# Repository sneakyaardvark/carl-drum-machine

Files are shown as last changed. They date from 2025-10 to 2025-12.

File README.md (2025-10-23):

# C.A.R.L. — Clocked Asynchronous Rhythm Logician

**Team 05:**  
Bao Nguyen  
Andrew Stanton  
Christian Mickelson  
Ethan Budde  

---

## Overview
C.A.R.L. is a portable drum sequencer that lets users tap out, save, and play rhythmic patterns. It operates independently with onboard controls, display, and speaker.

---

## Features
- Sequences and plays drum beats  
- Onboard speaker and volume control  
- Standalone operation (no computer required)  
- 13 pushbuttons, LED indicators, LCD display  
- Optional MIDI, SD card, and battery power  

---

## Hardware
- **Processor:** ESP32  
- **Display:** 20×4 LCD  
- **Inputs:** 13 pushbuttons, 4 potentiometers  
- **Outputs:** LEDs, speaker (8 Ω), LCD  
- **Power:** 5 V barrel jack or optional battery  
- **Enclosure:** Laser-cut plywood + 3D printed parts  

---

## Development
- **Electronics:** KiCAD  
- **3D Design:** Fusion 360  
- **Firmware:** Arduino / PlatformIO

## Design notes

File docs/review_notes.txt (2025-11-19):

Team 8 reviews Team 5 11/18/2025
Nawaf, Nawaf
Andrew, Ethan, Christian, Bao

Number of sensors
 - 8 buttons for beat, each with 2 LEDs
 - Function buttons, play has 1 LED

Power supply
 - multiple regulators: 5V and 3.3V
 - multiple of each for temperature management
 - calculate power consumption
 - Use diodes for feedback / reverse polarity
 - 100uF or less caps close to ICs (decoupling caps)
 - USBC for power?
 - 0.5 for power traces
 - 0.3 for everything else

LED driver
 - 1 resistor controls voltage to all LEDs

Use different switch for power toggle (keyboard switch won't work)

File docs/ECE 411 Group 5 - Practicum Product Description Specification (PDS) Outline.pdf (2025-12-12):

### Team 05

Bao Nguyen
Andrew Stanton
Christian Mickelson
Ethan Budde
Practicum Product Design Specification (PDS)
- Short Descriptive Name
- C.A.R.L.: The Clocked Asynchronous Rhythm Logician, a drum machine made to interactively and portably create sequences of musical beats.
- Executive Summary with Concept of Operations (2 pts)
- A portable drum sequencer that plays and saves music sequences. Users can tap out a drum beat, save and clone patterns, and play back their beats through the on-board speaker. [Users can also apply basic effects and modulation to the sequence, for added customizability.]
- Brief “Market” Analysis (2 pts)
- Who are the intended customers / users?
■ Music students, hobbyists, and sound producers of all kinds.
- What is the competition? Why is your product different?
■ Competing with large name-brand musical equipment manufacturers (Korg, Yamaha, Roland, etc)
■ Also competing with more niche, hobbyist sound engineering products (teenage engineering, Analogue)
■ Our product/software is open source and customizable
■ No subscriptions, payment plans, DRM
■ No warranty-voiding internal hardware, fully repairable and destroyable!
- What price do you think you can sell this for, and why? (keep it short, we're engineers, not marketing researchers)
■ 50 dollars, since most commercial options are over $100.
- Requirements (4 pts)
- Must sequence music beats
- Must play back sequenced beats
- Must include a speaker
- Must include volume adjustment
- Must operate independently of a computer or other audio equipment
- Must have buttons for parameter changes
- Should have audio effects
- Should be contained in an enclosure
- Should have MIDI output
- Should have multiple tracks / polyphonic sound
- Should have display for polyphonic voice / pattern parameters
- May have audio line out
- May allow the user to add new sounds
- May be battery powered

- System Architecture (4 pts)
- Level 0

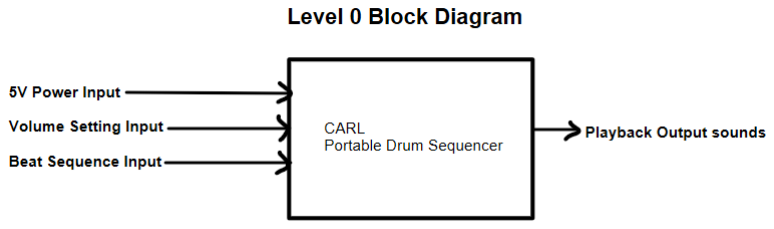
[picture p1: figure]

- Level 1

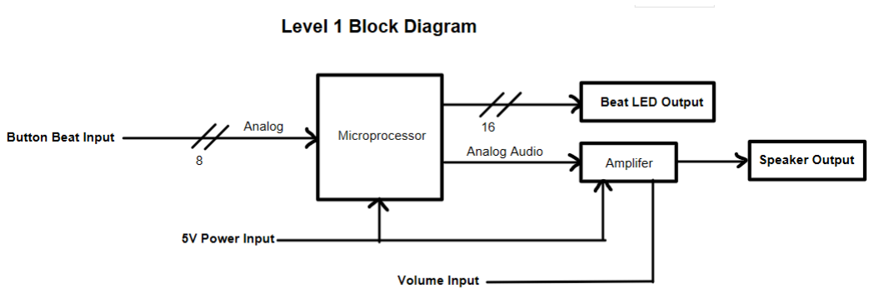
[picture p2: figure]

- Design Specification (4 pts)
- Sensors
■ Buttons: basic small switches ■ Volume: potentiometer
- Processor: ESP32
■ Firmware: Arduino framework
- Actuators
■ Beat LEDs
■ Speaker (8ohm speaker)
- Power
■ 5V from wall adapter
■ Optional battery power
- Mechanical Design
■ Enclosure: laser Cut plywood + 3d printed components
- Development environment
■ KiCAD
■ Fusion360
■ PlatformIO

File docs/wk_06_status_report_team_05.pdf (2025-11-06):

ECE411 HW Wk 06
Team 05
Bao Nguyen
Andrew Stanton
Christian Mickelson
Ethan Budde
Status Report: CARL Drum Machine The CARL drum machine MVP(Minimum Viable Product) is on-track for completion. There is a basic breadboard prototype for the controls and power supply, while the development boards for the audio components were delayed in shipping. They should arrive by the end of the week. The schematic and PCB layout are also going well. All necessary components are present and work can begin on polishing. The firmware is going very well, with a good framework and a number of abstractions already in place. Now that the hardware is well defined, the “glue” can be coded to tie the framework together with the hardware. Even with reasonable debug time, there should be time for extra features, such as multiple voices/polyphony.

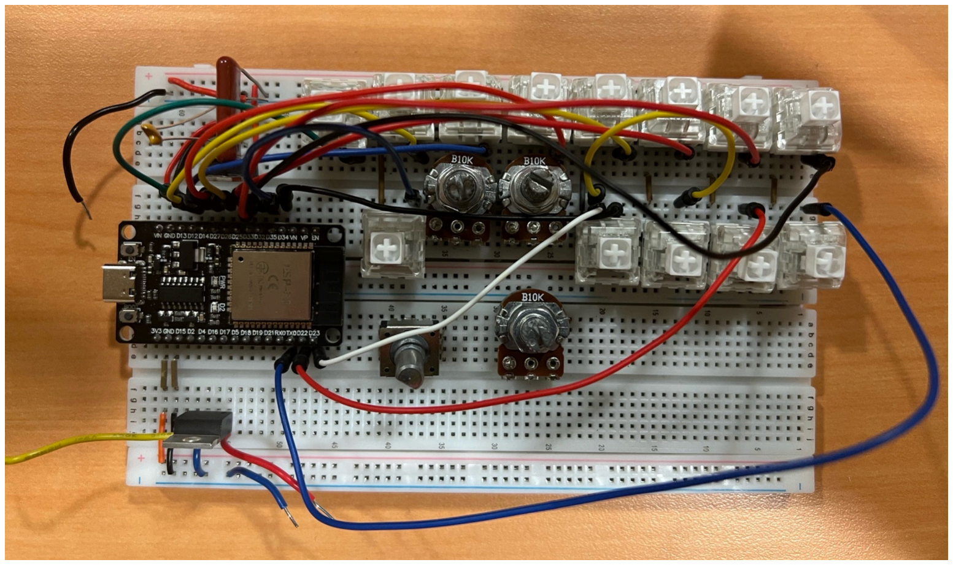
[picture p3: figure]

Breadboard prototype #1

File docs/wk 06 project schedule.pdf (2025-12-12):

ECE411 HW Wk 06
Team 05
Bao Nguyen
Andrew Stanton
Christian Mickelson
Ethan Budde
Project Schedule
We are using a GitHub project to manage our tasks and schedule. It is available here: https://github.com/users/sneakyaardvark/projects/1/views/4
Here is a preview screenshot (no .pdf export is available, sorry!)

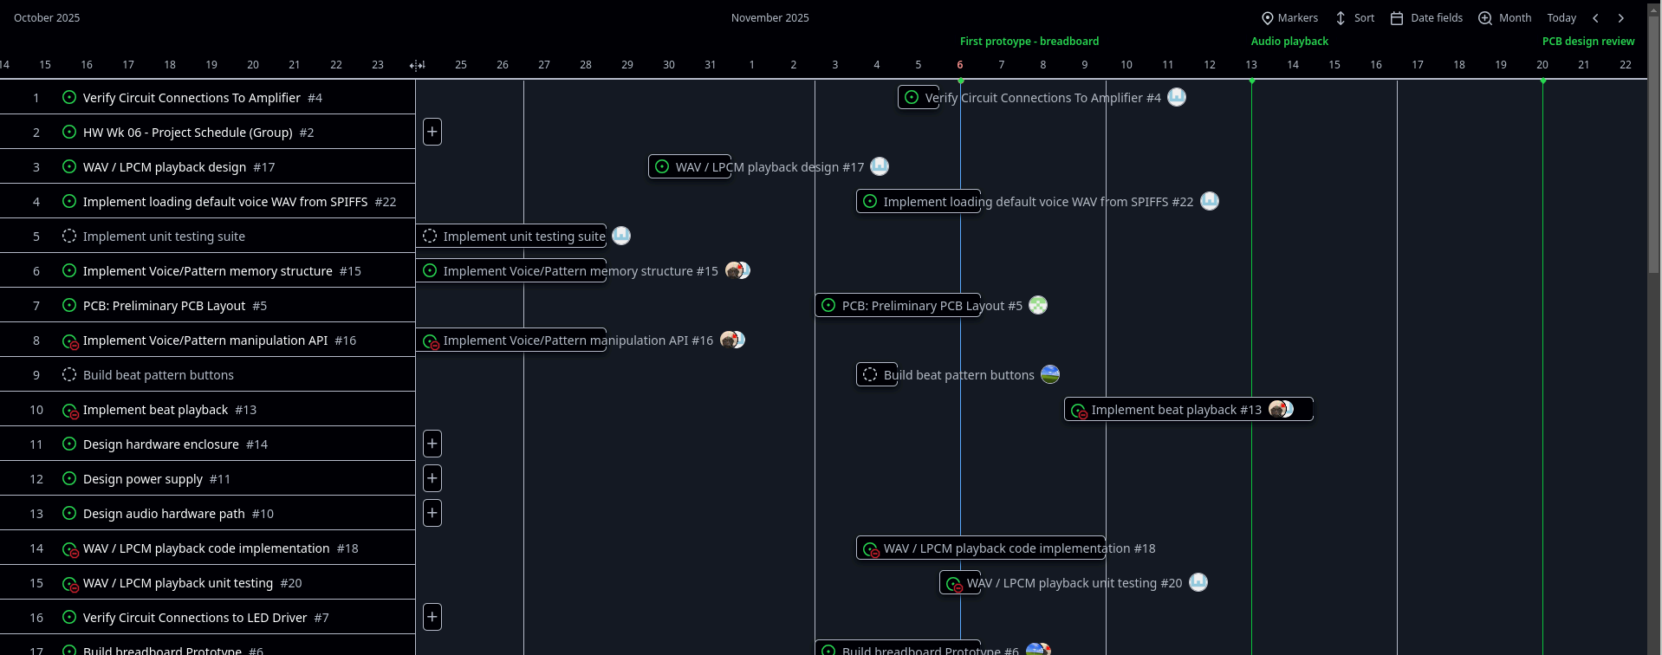
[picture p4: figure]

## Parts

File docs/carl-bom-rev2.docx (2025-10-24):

C.A.R.L. Drum Machine BOM
Rev. 2

# | Item Description | Qty | Function / Notes

1 | 8 Ω Speaker | 1 | Audio output
2 | Clear Plastic NO pushbuttons | 17 | Momentary inputs for user control
3 | Red LEDs | 8 | Visual feedback for downbeat notes
4 | Yellow LEDs | 8 | Visual feedback for backbeat notes
5 | Green LED | 1 | Playback indicator / metronome visualization
6 | Orange LED | 1 | MOD button indicator
7 | Potentiometers | 4 | Control parameters (volume, tempo, filtering)
8 | 20x5 LCD Display | 1 | System information display (voices, patterns)
9 | Speaker Op-Amp | 1 | Amplifying speaker output
10 | Fuses | 8 | Current fluctuation protection
11 | E-pin Jumpers | 4 | Debugging / circuit-level isolation
12 | Knobs | 4 | Potentiometer control
13 | 3.5 mm Audio Jack | 1 | Output for external audio device
14 | 2.5 mm Barrel Jack | 1 | DC power input port
15 | 9V Battery Terminals | 2 | Battery power input ports
16 | LED Driver | 1 | Arbitrate LED brightness and sequencing
17 | 3.3/5 V PS/MP Board | 1 | Power supplier / main control board
18 | SD Card Reader | 1 | External memory interface
19 | ESP32 Processor | 1 | Primary logic controller

ECE411 Group 5 Bao Nguyen Andrew Stanton Christian Mickelson Ethan Budde

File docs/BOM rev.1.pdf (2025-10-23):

# BOM rev.1

# | Item Description | Qty | Notes / Function

1 | 8 Ω Speaker | 1 | Audio output
2 | Clear Plastic Pushbuttons (N/O) - Keyboard type | 13 | Momentary inputs for user control
3 | Red LEDs (onbeat) | 8 | Visual beat indicators
4 | Orange/Yellow LEDs (offbeat) | 8 | Secondary timing indicators
5 | Green LED (power) | 1 | Power indicator
6 | Potentiometers | 4 | Control parameters (e.g. volume, filter, etc.)
7 | LCD Display (20×4 or 20×5) | 1 | System display
8 | Speaker Op-Amp | 1 | Amplifies speaker output
9 | Fuses | 8 | Over-current protection
10 | Jumpers (E-pin) | 4 | Debugging/isolation
11 | Knobs | 4 | For potentiometer shafts
12 | 3.5 mm Jack | 1 | Audio I/O
13 | Barrel Jack | 1 | DC power input
14 | LED Driver | 1 | Controls LED brightness and sequencing
15 | PS/MP Board (5 V / 3.3 V) | 1 | Power supply / main control board
16 | SD Card Reader | 1 | External memory interface
17 | ESP32 | 1 | Main microcontroller

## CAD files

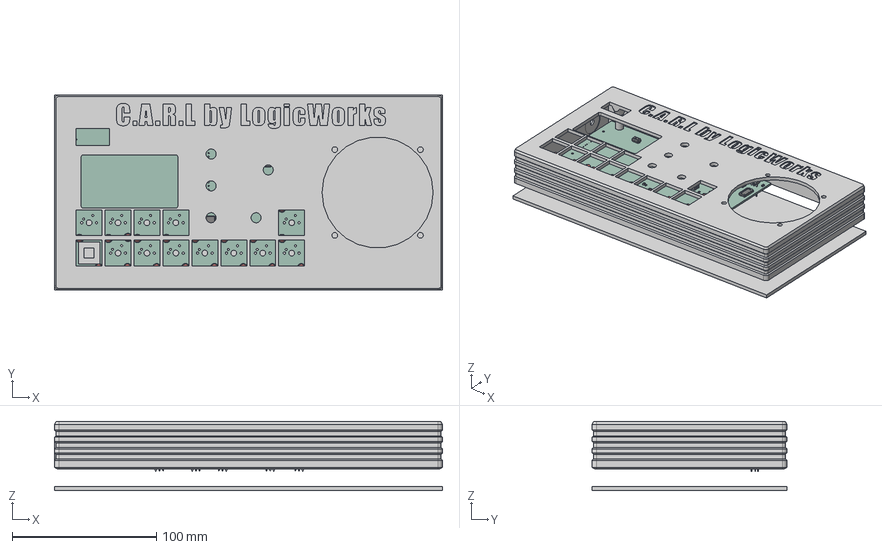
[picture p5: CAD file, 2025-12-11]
3D Models/Carl_Enclosure.step
269.0 x 135.0 x 48.0 mm
LED_D5.0mm x 18
HTSSOP-32-1EP_6.1x11mm_P0.65mm_EP5.2x11mm
C_0805_2012Metric x 15
PinHeader_1x02_P2.54mm_Vertical x 7
PinHeader_1x01_P2.54mm_Vertical x 9
TO-220-3_Vertical x 5
SOIC-28W_7.5x17.9mm_P1.27mm
R_0805_2012Metric x 4
SW_DIP_SPSTx01_Slide_6.7x4.1mm_W6.73mm_P2.54mm_LowProfile_JPin
Speaker_CUI_CMR-1206S-67
CARL_PCB

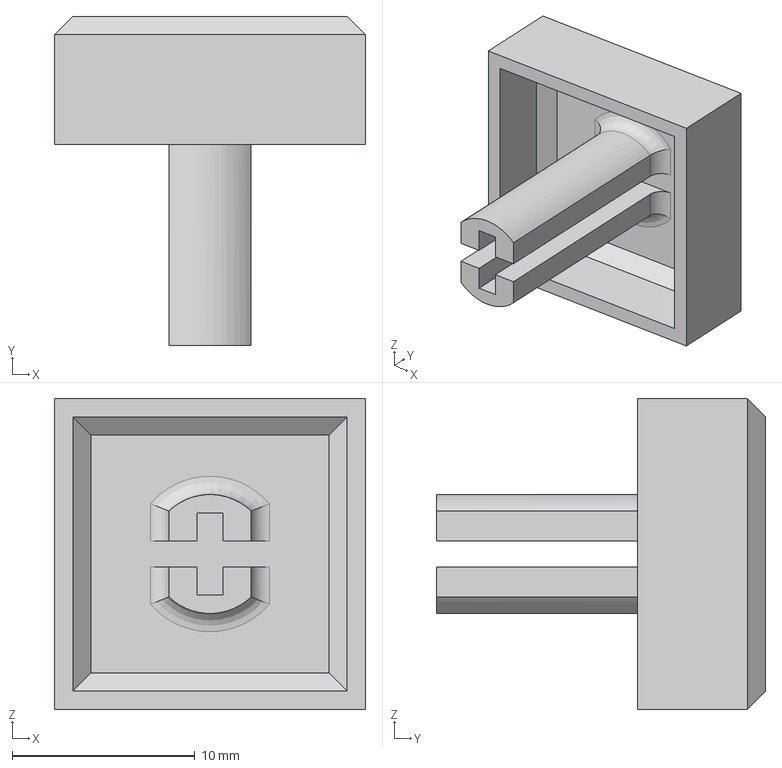
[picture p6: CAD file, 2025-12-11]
3D Models/Carl_Keycap.step
17.0 x 18.0 x 17.0 mm

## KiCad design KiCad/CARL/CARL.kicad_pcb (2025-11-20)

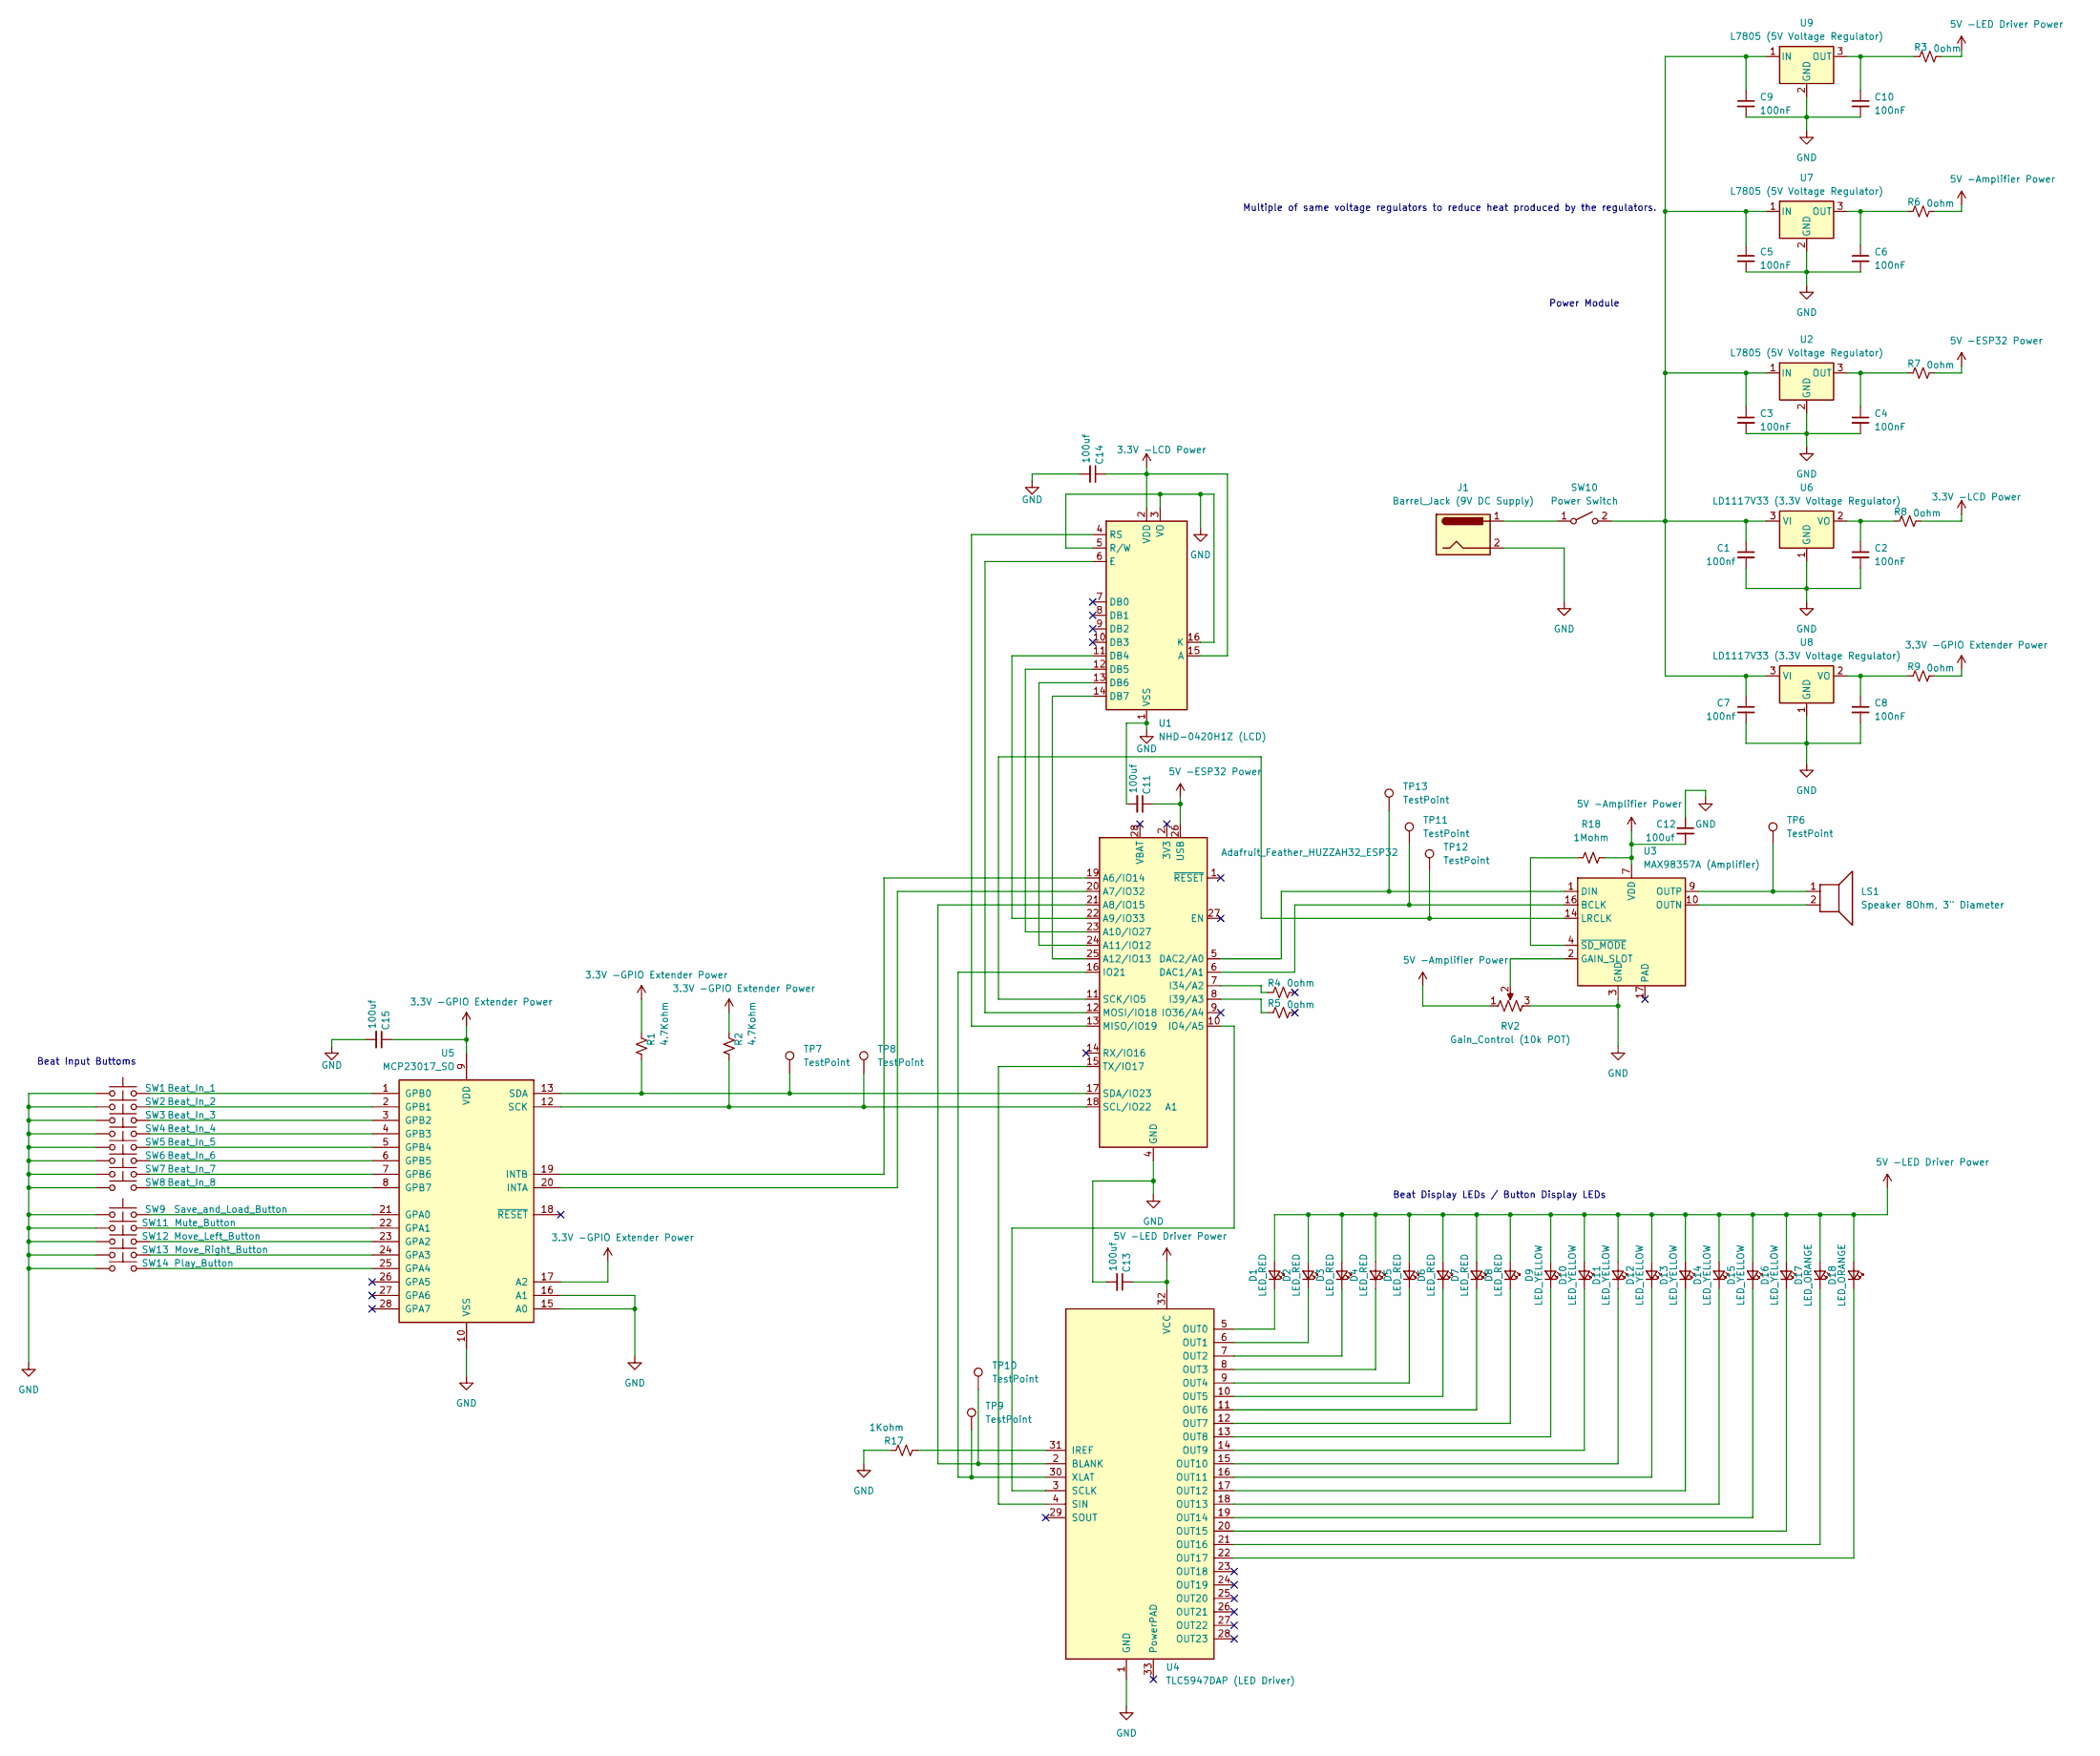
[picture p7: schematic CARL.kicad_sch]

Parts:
A1: Adafruit_Feather_HUZZAH32_ESP32; Adafruit_Feather
C1, C7: 100nf; C_0805_2012Metric
C2, C3, C4, C5, C6, C8, C9, C10: 100nF; C_0805_2012Metric
C11, C12, C13, C14, C15: 100uf; C_0805_2012Metric
D1, D2, D3, D4, D5, D6, D7, D8: LED_RED; LED_D5.0mm
D9, D10, D11, D12, D13, D14, D15, D16: LED_YELLOW; LED_D5.0mm
D17, D18: LED_ORANGE; LED_D5.0mm
J1: Barrel_Jack (9V DC Supply); BarrelJack_CUI_PJ-036AH-SMT_Horizontal
LS1: Speaker 8Ohm, 3" Diameter; Speaker_CUI_CMR-1206S-67
R1, R2: 4.7Kohm; R_0805_2012Metric
R3, R4, R5, R6, R7, R8, R9: 0ohm; PinHeader_1x02_P2.54mm_Vertical
R17: 1Kohm; R_0805_2012Metric
R18: 1Mohm; R_0805_2012Metric
RV2: Gain_Control (10k POT); Potentiometer_ACP_CA6-VSMD_Vertical
SW1: Beat_In_1; SW_Cherry_MX_1.00u_PCB
SW2: Beat_In_2; SW_Cherry_MX_1.00u_PCB
SW3: Beat_In_3; SW_Cherry_MX_1.00u_PCB
SW4: Beat_In_4; SW_Cherry_MX_1.00u_PCB
SW5: Beat_In_5; SW_Cherry_MX_1.00u_PCB
SW6: Beat_In_6; SW_Cherry_MX_1.00u_PCB
SW7: Beat_In_7; SW_Cherry_MX_1.00u_PCB
SW8: Beat_In_8; SW_Cherry_MX_1.00u_PCB
SW9: Save_and_Load_Button; SW_Cherry_MX_1.00u_PCB
SW10: Power Switch; SW_DIP_SPSTx01_Slide_6.7x4.1mm_W6.73mm_P2.54mm_LowProfile_J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
SW11: Mute_Button; SW_Cherry_MX_1.00u_PCB
SW12: Move_Left_Button; SW_Cherry_MX_1.00u_PCB
SW13: Move_Right_Button; SW_Cherry_MX_1.00u_PCB
SW14: Play_Button; SW_Cherry_MX_1.00u_PCB
TP6, TP7, TP8, TP9, TP10, TP11, TP12, TP13: TestPoint; PinHeader_1x01_P2.54mm_Vertical
U1: NHD-0420H1Z (LCD); NHD-0420H1Z
U2, U7, U9: L7805 (5V Voltage Regulator); TO-220-3_Vertical
U3: MAX98357A (Amplifier); TQFN-16-1EP_3x3mm_P0.5mm_EP1.23x1.23mm
U4: TLC5947DAP (LED Driver); HTSSOP-32-1EP_6.1x11mm_P0.65mm_EP5.2x11mm_Mask4.11x4.36mm_T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
U5: MCP23017_SO; SOIC-28W_7.5x17.9mm_P1.27mm
U6, U8: LD1117V33 (3.3V Voltage Regulator); TO-220-3_Vertical

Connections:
3.3V -GPIO Extender Power: C15.1, R1.1, R2.1, R9.2, U5.9 (VDD), U5.17 (A2)
3.3V -LCD Power: C14.1, R8.2, U1.2 (VDD), U1.15 (A); also elsewhere on the board
5V -Amplifier Power: C12.2, R6.2, R18.2, RV2.1, U3.7 (VDD), U3.8 (VDD)
5V -ESP32 Power: A1.26 (USB), C11.1, R7.2
5V -LED Driver Power: C13.1, D1.2 (A), D2.2 (A), D3.2 (A), D4.2 (A), D5.2 (A), D6.2 (A), D7.2 (A), D8.2 (A), D9.2 (A), D10.2 (A), D11.2 (A), D12.2 (A), D13.2 (A), D14.2 (A), D15.2 (A), D16.2 (A), D17.2 (A), D18.2 (A), R3.2, U4.32 (VCC)
GND: A1.4 (GND), C1.2, C2.2, C3.2, C4.2, C5.2, C6.2, C7.2, C8.2, C9.2, C10.2, C11.2, C12.1, C13.2, C14.2, C15.2, J1.2, R17.1, RV2.3, SW1.1, SW2.1, SW3.1, SW4.1, SW5.1, SW6.1, SW7.1, SW8.1, SW9.1, SW11.1, SW12.1, SW13.1, SW14.1, U1.1 (VSS), U1.3 (VO), U1.5 (R/W), U1.16 (K), U2.2 (GND), U3.3 (GND), U3.11 (GND), U3.15 (GND), U4.1 (GND), U5.10 (VSS), U5.15 (A0), U5.16 (A1), U6.1 (GND), U7.2 (GND), U8.1 (GND), U9.2 (GND)
unnamed: A1.19 (A6/IO14), U5.19 (INTB)
unnamed: A1.20 (A7/IO32), U5.20 (INTA)
unnamed: A1.21 (A8/IO15), TP10.1, U4.2 (BLANK)
unnamed: A1.22 (A9/IO33), U1.11 (DB4)
unnamed: A1.23 (A10/IO27), U1.12 (DB5)
unnamed: A1.24 (A11/IO12), U1.13 (DB6)
unnamed: A1.25 (A12/IO13), U1.14 (DB7)
unnamed: A1.6 (DAC1/A1), TP11.1, U3.16 (BCLK)
unnamed: A1.5 (DAC2/A0), TP13.1, U3.1 (DIN)
unnamed: A1.7 (I34/A2), R4.1
unnamed: A1.8 (I39/A3), R5.1
unnamed: A1.10 (IO4/A5), U4.3 (SCLK)
unnamed: A1.16 (IO21), TP9.1, U4.30 (XLAT)
unnamed: A1.13 (MISO/IO19), U1.4 (RS)
unnamed: A1.12 (MOSI/IO18), U1.6 (E)
unnamed: A1.11 (SCK/IO5), TP12.1, U3.14 (LRCLK)
unnamed: A1.18 (SCL/IO22), R2.2, TP8.1, U5.12 (SCK)
unnamed: A1.17 (SDA/IO23), R1.2, TP7.1, U5.13 (SDA)
unnamed: A1.15 (TX/IO17), U4.4 (SIN)
unnamed: D1.1 (K), U4.5 (OUT0)
unnamed: D2.1 (K), U4.6 (OUT1)
unnamed: D3.1 (K), U4.7 (OUT2)
unnamed: D4.1 (K), U4.8 (OUT3)
unnamed: D5.1 (K), U4.9 (OUT4)
unnamed: D6.1 (K), U4.10 (OUT5)
unnamed: D7.1 (K), U4.11 (OUT6)
unnamed: D8.1 (K), U4.12 (OUT7)
unnamed: D9.1 (K), U4.13 (OUT8)
unnamed: D10.1 (K), U4.14 (OUT9)
unnamed: D11.1 (K), U4.15 (OUT10)
unnamed: D12.1 (K), U4.16 (OUT11)
unnamed: D13.1 (K), U4.17 (OUT12)
unnamed: D14.1 (K), U4.18 (OUT13)
unnamed: D15.1 (K), U4.19 (OUT14)
unnamed: D16.1 (K), U4.20 (OUT15)
unnamed: D17.1 (K), U4.21 (OUT16)
unnamed: D18.1 (K), U4.22 (OUT17)
unnamed: J1.1, SW10.1 (A)
unnamed: C1.1, C3.1, C5.1, C7.1, C9.1, SW10.2 (B), U2.1 (IN), U6.3 (VI), U7.1 (IN), U8.3 (VI), U9.1 (IN)
unnamed: C4.1, R7.1, U2.3 (OUT)
unnamed: RV2.2, U3.2 (GAIN_SLOT)
unnamed: LS1.2, U3.10 (OUTN)
unnamed: LS1.1, TP6.1, U3.9 (OUTP)
unnamed: R18.1, U3.4 (~SD_MODE)
unnamed: R17.2, U4.31 (IREF)
unnamed: SW9.2, U5.21 (GPA0)
unnamed: SW11.2, U5.22 (GPA1)
unnamed: SW12.2, U5.23 (GPA2)
unnamed: SW13.2, U5.24 (GPA3)
unnamed: SW14.2, U5.25 (GPA4)
unnamed: SW1.2, U5.1 (GPB0)
unnamed: SW2.2, U5.2 (GPB1)
unnamed: SW3.2, U5.3 (GPB2)
unnamed: SW4.2, U5.4 (GPB3)
unnamed: SW5.2, U5.5 (GPB4)
unnamed: SW6.2, U5.6 (GPB5)
unnamed: SW7.2, U5.7 (GPB6)
unnamed: SW8.2, U5.8 (GPB7)
unnamed: C2.1, R8.1, U6.2 (VO)
unnamed: C6.1, R6.1, U7.3 (OUT)
unnamed: C8.1, R9.1, U8.2 (VO)
unnamed: C10.1, R3.1, U9.3 (OUT)

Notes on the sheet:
Beat Input Buttoms
Multiple of same voltage regulators to reduce heat produced by the regulators.
Power Module
Beat Display LEDs / Button Display LEDs

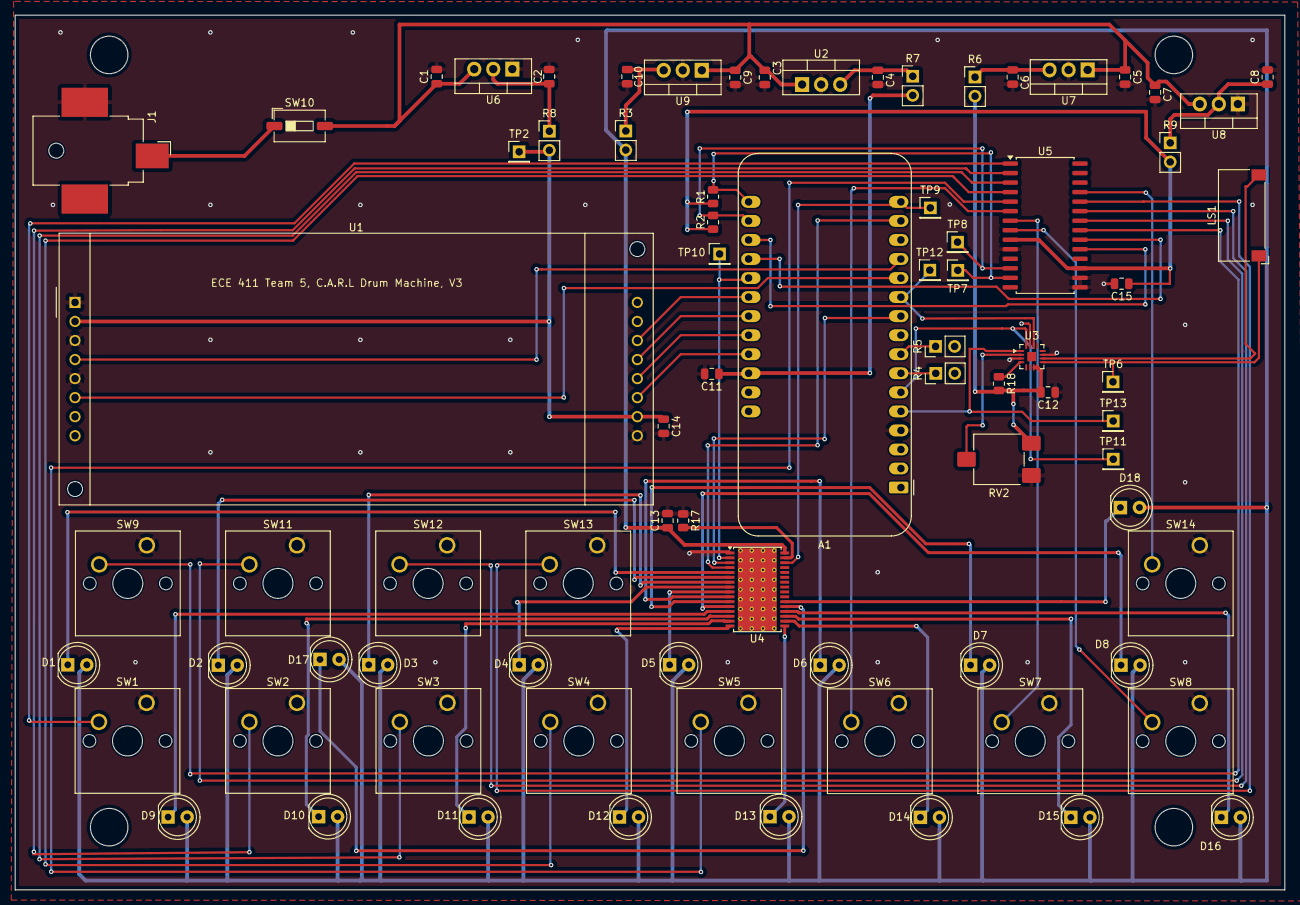
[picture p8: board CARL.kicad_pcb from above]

Board: 2 copper layers, 169.3 x 116.7 mm, 80 parts (0 on the bottom side), 68 nets.

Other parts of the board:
TP2: TestPoint; PinHeader_1x01_P2.54mm_Vertical

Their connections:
3.3V -LCD Power: TP2.1; also elsewhere on the board

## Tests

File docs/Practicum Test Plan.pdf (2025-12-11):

Project Title: CARL
Team Name: Group 5
Team Members: Andrew Stanton, Bao Nguyen, Christian Mickelson, Ethan Budde Date:12/3/2025

Practicum Test Plan
This test plan is an outline on how C.A.R.L drum machines will be tested to make sure it works as designed. This document includes a test for each sub system, verification test for the main functions, and validation test showing the final system meets all project requirements. The goal is to confirm every part of the design from power, inputs, and outputs functions correctly and reliably in the finished product.

### Unit Testing

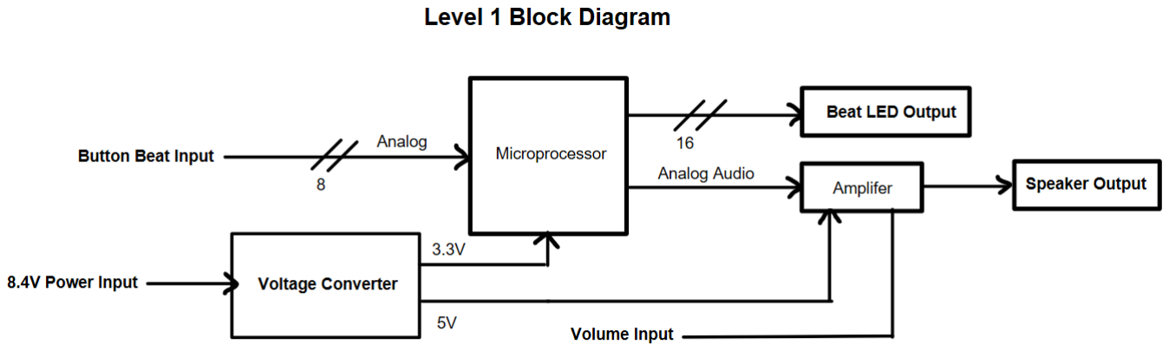
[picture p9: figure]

Fig 1. L1 block diagram

Unit Test ID | Block ID | Test Description
UT-01 | 2s Power Input | Verify 2s power are being delivered to 5V and 3V Voltage Regulator
UT-02 | 5V Power Output | Verify 5V out for the LED driver and Amplifier
UT-03 | 3V Power Output | Verify 3V out for the Microprocessor, LCD, and GPIO expander
UT-04 | Beat Button Input | Confirm Pressing the button sends digital signal to uP
UT-05 | Volume Pot | Verify volume is adjustable Via Pot
UT-06 | Beat LED Output | Verify Beat LED output expected behavior based on button inputs.
UT-07 | Amplifier | Verify Ampliter increase audio signal
UT-08 | Speaker Output | Confirm speaker output sound
UT-09 | Micropressesor | Test GPIO outputs with a logic analyzer

### Verification Test

Verification Test ID | Function / Feature | Test Description
VT-01 | Beat Button input | Verify pressing beat buttons record beat into the sequencer
VT-02 | Sequence playback | After VT-01, press play and observe the selected beats play back
VT-03 | Volume Control | Check that adjusting the volume knob changes the volume of the output sound
VT-04 | Beat LED | Verify the Beat LED flashes in respect to the sequencer clock
VT-05 | Pattern saving/cloning | After VT-01, press the save button, cycle to a different track, and paste. Observe that the same pattern is copied to the new track
VT-06 | Pattern switching | Confirm the switching pattern updates playback to the new pattern
VT-07 | System start up | Make sure it turns on in a default state.
VT-08 | Speaker output check | Verify speaker output is clean audio sound.

### Validation Tests

Validation Test ID | Requirement(Must/Should/May) | Validation Test Description
VAL-01 | Must sequence music beats | Verify that the user can enter a series of button presses and the system stores them as a beat sequence.
VAL-02 | Must play back sequenced beats | Confirm that a stored beat sequence can be played back in a repeating loop through the speaker.
VAL-03 | Must include a speaker | Verify that the product enclosure includes a functioning speaker connected to the audio output.
VAL-04 | Must include volume adjustment | Confirm that the user can adjust the volume and that the audio level changes over a usable range.
VAL-05 | Must operate independently of a computer or other audio equipment | Verify that the system can power on, sequence, and play beats with only its own power source and controls.
VAL-06 | Must have buttons for parameter changes | Confirm that physical buttons exist for changing parameters and that each button reliably changes at least one parameter.
VAL-07 | Must be contained in an enclosure | Verify that all electronics are mounted in a physical enclosure suitable for normal handling and use.
VAL-08 | Should have audio effects | Confirm that at least one audio effect can be enabled and that it audibly changes the output.

VAL-09 | Should have MIDI output | Verify that MIDI output signals are produced according to documented mapping when beats are played.
VAL-10 | Should have multiple tracks | Confirm that at least two different sounds can play simultaneously in a single pattern.
VAL-11 | Should have display for polyphonic voice | Verify that the display shows information about tracks/voices or pattern parameters while editing/playing.
VAL-12 | May have audio line out | Confirm that, if implemented, an audio line-out jack produces the same signal as the speaker output at line level.
VAL-13 | May allow the user to add new sounds | Verify that the user can load or select new sounds and use them in a sequence.
VAL-14 | May be battery powered | Confirm that the system can run from batteries for a reasonable operating time without external power.

Example Test Case
Test Author: Bao Nguyen
Test Case Name: | 2S Power Input to Voltage Regulator Output Test | Test ID #: | TC-UT-01
Description: | This test verifies that the main 2S power input correctly feeds the 5V and 3.3V voltage regulators and that each regulator outputs the correct voltage. This test covers Unit Test UT-01, UT-02, and UT-03. | Type: | ☑ white box □ black box □ ________

Tester Information
| Name of Tester: | | Date:
| HW/SW Version: | Prototype v1.0 | Time:
| Setup: | Connect the 2S battery or bench power supply to the system input. Use a multimeter to measure the 5V and 3.3V regulator output pads or test points,
S T E P | Action | Expected Result | P A S S | F A I L | N / A | Comments
1 | Connect 2S battery or bench supply (6-8.4V) to main input. | System powers on, no smoke, noise, or overheating.
2 | Measure input voltage at regulator VIN pin. | VIN read between 6.0-8.4V
3 | Measure 5V regulator output. | Steady 5.00V ~ +/- 5% ripple
4 | Measure 3.3V regulator output | Steady 3.30V ~ +/- 5% ripple
5 | Power on LED driver and measure 5V under load | Minimum 3.0V maximum 5.5V
6 | Turn on amplifier by playing music and check 5V rail | Voltage does not sag below 4.85V.
7 | Power on the microprocessor and measure 3.3V rail under load. | Voltage is within 3V - 3.5V
8 | Touch regulator to make sure its not burning up | Should be warm and not hot.
9 | Disconnect power | System powers off normally

Overall test result:

Example Matrix Test (for varying parameters)

Test Author: Bao Nguyen

Test Case Name: | Voltage Regulator Stability Test | Test ID #: | MT-PS-01
Description: | Verify that the 5V and 3.3V voltage regulators maintain proper output voltage across a range of input voltages and system loads. Ensures stable operation under typical and extreme battery conditions. | Type: | □ white box ☑ black box □ ________ _____

Tester Information

| Name of Tester: | | Date:
| HW/SW Version: | Prototype v1.0 | Time:
| Setup: | Use a bench power supply in place of the 2S battery. Connect the supply to system input and measure 5V and 3.3V rails at their respective test points with a digital multimeter. Power on loads (LED driver, amplifier, full system) where noted.
T E S T | INPUTS | EXPECTED OUTPUTS | P A S S | F A I L | N / A | Comment s
Expected 5V Output | Expected 3.3V Output
1 | VIN = 6.0V (low battery) | 4.80–5.10V | 3.00–3.35V
2 | 7.4V (nominal 2S) | 4.80–5.10V | 3.00–3.35V
3 | 8.4V (full 2S charge) | 4.80–5.10V | 3.00–3.35V
4 | 8.4V + LED Driver Load | 4.80–5.10V | 3.00–3.35V
5 | 8.4V + Amplifier Load | 4.80–5.10V | 3.00–3.35V
6 | 6.0V + Full system load | No brown out | No brown out
| Overall test result:

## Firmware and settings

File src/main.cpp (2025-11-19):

#include "config.h"
#include <Arduino.h>
#include <BeatPattern.hpp>
#include <WAVFile.hpp>
#include <SPIFFS.h>
#include <I2SOutput.hpp>

struct carl {
  uint8_t current_voice = 0;
  beat_pattern pattern_mtx[NUM_VOICES][NUM_PATTERNS];
  uint8_t tempo = DEFAULT_TEMPO; 
};

struct carl CARL;

void setup() {
  Serial.begin(115200);
  if (!SPIFFS.begin(true)) {
    Serial.println("Error mounting SPIFFS");
    return;
  }
  Serial.println("starting I2S...");
  I2SOutput *output = new I2SOutput();
  output->begin();
  Serial.println("I2S started!");

  Serial.println("Loading WAV...");
  WAVFile *file = new WAVFile("/sine.wav", 128);
  Serial.println("WAV loaded!");
  Serial.println("Playing in 2.0 seconds...");
  delay(2);
  output->add(file, 1.0f);
}

void loop() {}

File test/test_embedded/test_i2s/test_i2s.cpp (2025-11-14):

#include <Arduino.h>
#include <ESP_I2S.h>
#include <unity.h>

void i2s_test_loop();
void i2s_test_setup();

int runUnityTests(void) {
  UNITY_BEGIN();
  return UNITY_END();
}
void setup() {
  delay(2000);
  i2s_test_setup();

  runUnityTests();
}

void loop() {
  i2s_test_loop();
}

// The GPIO pins are not fixed, most other pins could be used for the I2S function.
// #define I2S_LRC 36 // A4
// #define I2S_BCLK 39 // A3
// #define I2S_DIN 34 // A2
#define I2S_LRC  25 // A1
#define I2S_BCLK 5 // SCK
#define I2S_DIN  26 // A0


const int frequency = 440;    // frequency of square wave in Hz
const int amplitude = 500;    // amplitude of square wave
const int sampleRate = 8000;  // sample rate in Hz

i2s_data_bit_width_t bps = I2S_DATA_BIT_WIDTH_16BIT;
i2s_mode_t mode = I2S_MODE_STD;
i2s_slot_mode_t slot = I2S_SLOT_MODE_STEREO;

const unsigned int halfWavelength = sampleRate / frequency / 2;  // half wavelength of square wave

int32_t sample = amplitude;  // current sample value
unsigned int count = 0;

I2SClass i2s;


void i2s_test_setup() {
  Serial.begin(115200);
  Serial.println("I2S simple tone");

  i2s.setPins(I2S_BCLK, I2S_LRC, I2S_DIN);

  // start I2S at the sample rate with 16-bits per sample
  if (!i2s.begin(mode, sampleRate, bps, slot)) {
    Serial.println("Failed to initialize I2S!");
    while (1);  // do nothing
  }

}

void i2s_test_loop() {
  if (count % halfWavelength == 0) {
    // invert the sample every half wavelength count multiple to generate square wave
    sample = -1 * sample;
  }

  // Left channel, the low 8 bits then high 8 bits
  i2s.write(sample);
  i2s.write(sample >> 8);

  // Right channel, the low 8 bits then high 8 bits
  i2s.write(sample);
  i2s.write(sample >> 8);

  // increment the counter for the next sample
  count++;

}

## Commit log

2025-10-23 Add files via upload
    BOM Rev.1
2025-10-24 revised BOM, reorganized existing file structure for docs
2025-10-28 feat: use newest arduino-esp32 via pioarduino
2025-10-28 feat: update gitignore for kicad; reformat
2025-10-29 WIP KiCad Schematic
    Work in progress KiCad schematic containing the microcontroller, LCD, and LED driver along with LEDs it drives.
    [CARL.kicad_pcb, CARL.kicad_sch]
2025-10-30 Update CARL.kicad_sch
    Edited button layout to work correctly and removed resistors so we can instead utilize the ESP32's built in pullup resistor functionality.
    [CARL.kicad_sch]
2025-10-31 Preliminary Schematic Revision 2
    Fixed connections to LCD. Edited connections to Amplifier to (hopefully) work. Added GPIO extender and moved all button connections off of the esp32 and onto the extender.
    [CARL.kicad_sch]
2025-11-06 Schematic Update / Preliminary PCB
    -Added remaining LEDs to the schematic
    -Edited some connections with the amplifier to function correctly (hopefully)
    -Edited connections between LEDs and LED driver to correspond with what the data sheet shows. The LEDs now receive VCC instead of GND and all resistors have been removed from them with a new one added on the IREF pin.
    [CARL.kicad_pcb, CARL.kicad_sch]
2025-11-13 PCB V2 and Schematic V3
    -Updated schematic to utilize new voltage regulator setup.
    -Updated PCB to reflect changes done in the schematic
    [CARL.kicad_pcb, CARL.kicad_sch]
2025-11-14 docs: better explanation of sample manipulation
2025-11-14 fix: use data types more directly (PCM samples are signed), change func params where needed
2025-11-14 fix: offset frames address by buffer position
2025-11-18 Minor Schematic Update
    [CARL.kicad_sch]
2025-11-18 docs: add pcb review notes
2025-11-19 Merge branch 'sample-streaming'
    Squashed commit of the following:
    commit e3bee00b376309e504e5cf92ba370c6b4a4fad70
    Author: Sneaky Aardvark <81195290+sneakyaardvark@users.noreply.github.com>
    Date: Tue Nov 18 16:18:13 2025 -0800
    test: add test for i2s streaming
    commit 19241e77e7c422783674baf48b3c57fb1aa4e470
    Author: Sneaky Aardvark <81195290+sneakyaardvark@users.noreply.github.com>
    Date: Tue Nov 18 16:17:37 2025 -0800
    fix: prefetch all samples since synchronous load isn't working
    commit 91e38fa9a8a1fdda1b2329c217abf80ed29921a1
    Author: Sneaky Aardvark <81195290+sneakyaardvark@users.noreply.github.com>
    Date: Tue Nov 18 14:02:05 2025 -0800
    feat: set project debug log level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
    [main.cpp, test_stream.cpp]
2025-11-20 Final Schematic and PCB
    -Added test points and 0 ohm resistors to the schematic.
    -Added pullup resistors to I2C line
    -Updated PCB and redid layout according to updated schematic.
    -LED footprint updated to typical through hole PCB.
    -Generated Gerbur Files
    -Added Mounting Holes and Silkscreen
    [CARL.kicad_pcb, CARL.kicad_sch]
2025-12-02 increase number of I2S frames sent per I2S tick
2025-12-11 Add files via upload
    All printed mechanical parts for the enclosure.
    [Carl_Enclosure.step, Carl_Keycap.step]
2025-12-11 Load in 3D Models
    [Carl_Enclosure.step, Carl_Keycap.step]
